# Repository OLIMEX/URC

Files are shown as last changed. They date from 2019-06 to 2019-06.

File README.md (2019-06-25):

# URC
Universal Remote Control soldering kit

How to transfer a command from a remote control to the Olimex URC module:

1. Enter learning mode - press and hold both buttons until red LED turns on, then release both buttons;
2. Assing a button for the new comamnd - press button 1 or button 2 until LED blinks few times then release the button; the red LED remains on;
3. Programming - point the front of the Olimex URC module to the remote control; then press and hold the command you wish to store until the red LED turns off.

## License
* License for the software is GPL3
* License for the hardware is CERN OHL v1.2
* License for the documentation is CC-BY-SA-3.0

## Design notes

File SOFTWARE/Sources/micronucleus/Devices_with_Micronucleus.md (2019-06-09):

# List of devices with Micronucleus (incomplete) #

Micronucleus is widely used on thousands of open hardware product by different vendors. Please submit a pull request to add your own devices to this list, in case you design new hardware employing the Micronucleus bootloader.

Please note that Micronucleus is a completely independent project and is not afilliated in any way with the vendors mentioned below.

## ATtiny85 ##

- [Digispark](http://digistump.com/products/1) by [Digistump](digistump.com) - Widely spread tiny USB Developmentboard with Arduino-Support.

- [Olimexino 85](https://www.olimex.com/Products/Duino/AVR/open-source-hardware) by [Olimex](https://www.olimex.com) - Several different devboards fully assembled or as kits with USB interface

- [Usblinky](https://metalab.at/wiki/Usblinky) by [Metalab](https://metalab.at) - Tiny USB controller for WS2812 RGB LEDs.

- [Nanite 85](https://cpldcpu.wordpress.com/2014/04/25/the-nanite-85/) - Smallest useable ATtiny85 devboard. Approximates DIP ATtiny85 form factor.

- [Wattuino Nanite 85](http://www.watterott.com/en/Wattuino-Nanite85) by [Watterott](http://www.watterott.com) - Manufacturable redesign of the Nanite 85

- [BBtech ATtiny85 board](https://www.tindie.com/products/BBTech/attiny85-usb-development-tool-board/) - Well designed ATtiny85 board in Trinket form factor. Discontinued(?)

- [Iteadduino Tiny](http://imall.iteadstudio.com/im130615003.html) by Itead

- [Pro Nano 85](http://www.jayconsystems.com/pro-nano-50v-attiny85.html) by Jaconsystems

- [LaborTageBadge2013](http://www.das-labor.org/wiki/LaborTageBadge2013) - Badge with ATtiny85

- [Franzininho](https://github.com/Franzininho/franzininho-diy-board) - Franzininho designed by Fábio Souza and Thalis Antunes for Arduino Day 2017 at São Paulo / Brazil.

- [TinyStick](https://gitlab.com/nonchip/tinystick) - A simple open source Attiny85 board in a "usb stick on PCB" form factor simply exposes ISP and PortB without any onboard LED/button pin hogging. by Kyra 'nonchip' Zimmer

## ATtiny 841 ##

- [Wattuino Nanite 841](http://www.watterott.com/de/Wattuino-Nanite841) - Extremely small devboard with ATtiny841. Approximates the form factor of a DIP package.

## ATtiny 167 ##

- [Digispark Pro](http://digistump.com/products/109) by [Digistump](digistump.com) - Digispark successor with more I/O and memory

## ATtiny 84 ##
- [Shinewave](https://github.com/GGreenwood/Shinewave) by [Electric Exploits](http://electricexploits.net/) - USB mods for GameCube controllers

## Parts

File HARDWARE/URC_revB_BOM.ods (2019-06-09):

Designation | Quantity | Designator | Package
SY7080 | 1 | U1 | SOT23-6
56.2K_1% | 1 | R5 | R_0603_5MIL_DWS
100K_1% | 1 | R4 | R_0603_5MIL_DWS
4.7uH NRS4018T4R7MDGJ | 1 | L1 | CD43
SMD КОНД 0805 22 UF 6.3VDC | 3 | C1,C4,C6 | C_0805_5MIL_DWS
SMD КЛЮЧ ТАКТИЛЕН TSW66-V043R-100-LF / T1102NE 6x6x4.3mm | 2 | SW1,SW2
ИС VS1838B | 1 | U3 | RPM7236-V
SMD РЕЗ 0805 2 K 5% | 5 | R14,R13,R12,R10,R9 | R_0805_5MIL_DWS
СВЕТОДИОД IR IR333-A | 1 | LED2 | LED-5mm-PTH-KA
ATTINY85-20PU | 1 | U2 | SO-8
СЪЕДИНИТЕЛ BTH-DP-AA-LF (BH311P) | 1 | BAT1 | BATTERY-1xAA
SMD РЕЗ 1206 4.7 OHM 5% | 1 | R11 | R_1206_5MIL_DWS
SMD РЕЗ 0805 10 K 5% | 4 | R8,R6,R3,R2 | R_0805_5MIL_DWS
SMD РЕЗ 0805 100 K 5% | 1 | R7 | R_0805_5MIL_DWS
SMD РЕЗ 0805 22 K 5% | 1 | R1 | R_0805_5MIL_DWS
LED 3mm RED PTH | 1 | LED1 | LED-3mm-PTH-KA
WNM2016-3/TR | 1 | FET1 | SOT23
SMD КОНД 0805 2.2 UF | 3 | C5,C3,C2 | C_0805_5MIL_DWS

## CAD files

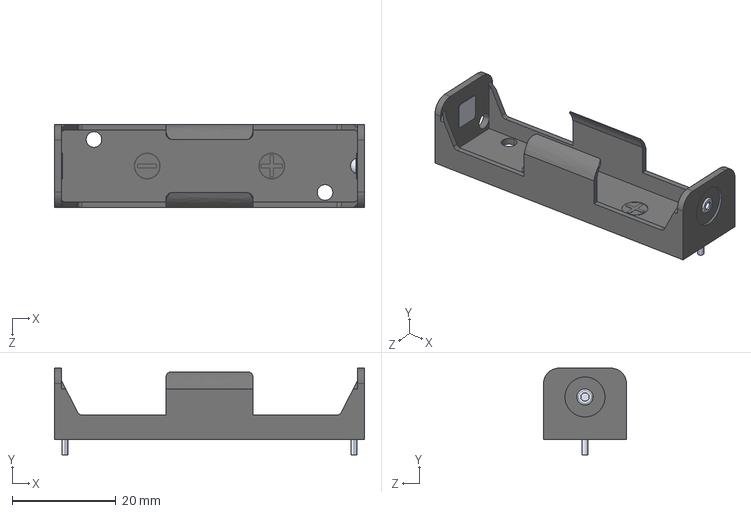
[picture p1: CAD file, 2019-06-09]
HARDWARE/3d/BAT_1xAA_HOLDER.step
59.7 x 16.7 x 16.0 mm

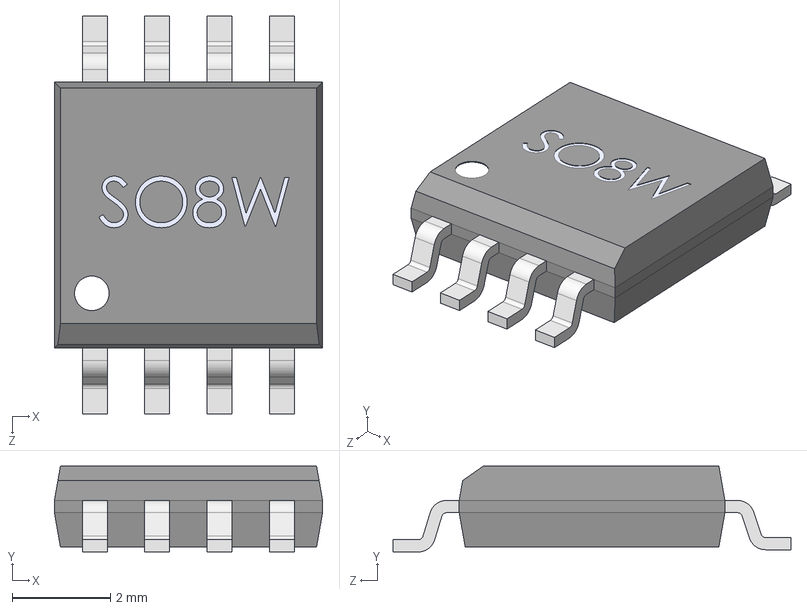
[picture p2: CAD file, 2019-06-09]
HARDWARE/3d/SO-8_208mil---SOIC8_Wide_5mmx5mm.step
5.46 x 1.75 x 8.10 mm

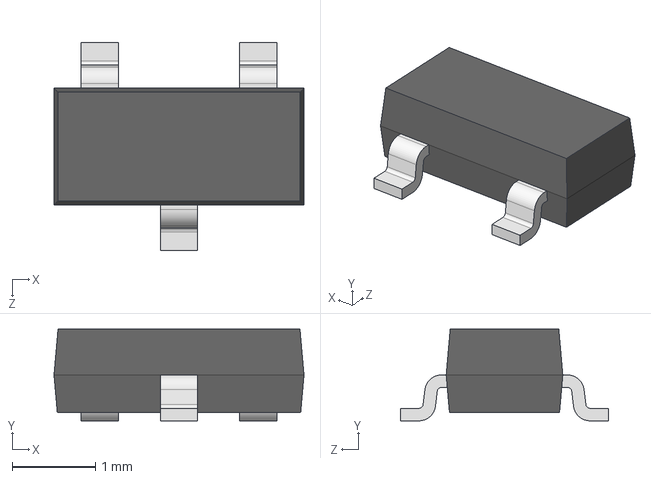
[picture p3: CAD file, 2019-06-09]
HARDWARE/3d/SOT-23.step
3.00 x 1.10 x 2.50 mm

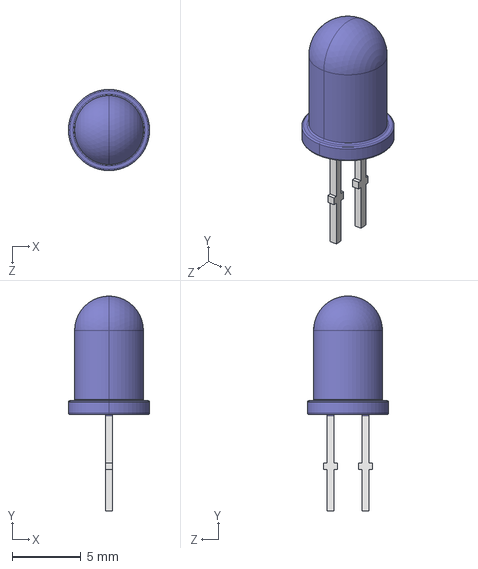
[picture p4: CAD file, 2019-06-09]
HARDWARE/3d/LED5MM.step
5.90 x 15.6 x 5.90 mm

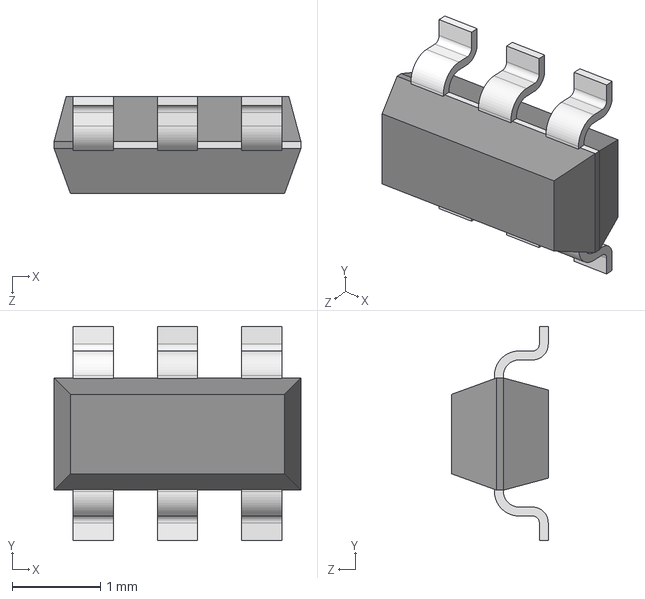
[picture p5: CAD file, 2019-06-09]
HARDWARE/3d/SOT-23-6.step
2.79 x 2.43 x 1.09 mm

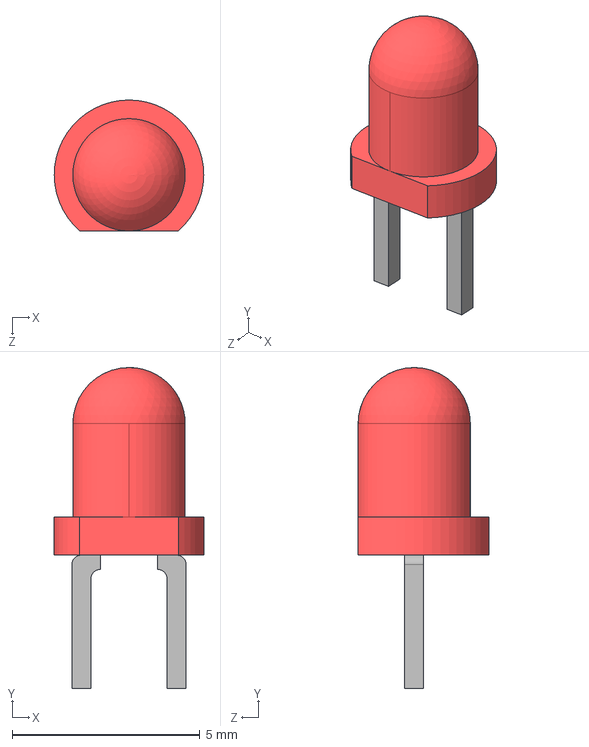
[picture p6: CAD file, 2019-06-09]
HARDWARE/3d/REDLED.step
3.99 x 8.56 x 3.49 mm

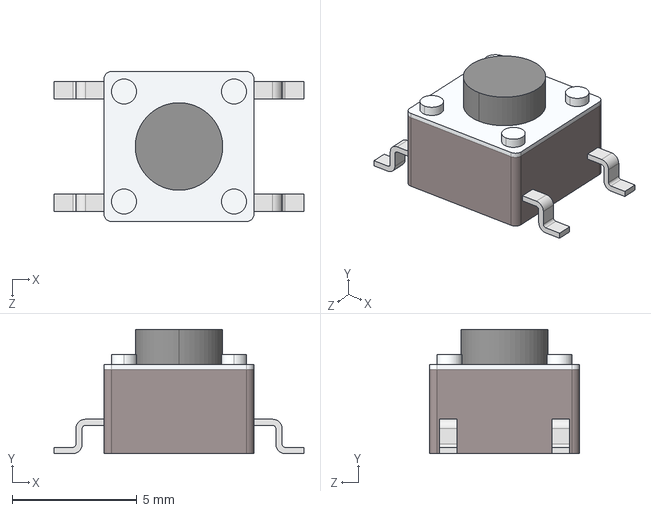
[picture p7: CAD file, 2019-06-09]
HARDWARE/3d/6mmTactileSwitch.step
10.0 x 4.97 x 6.00 mm

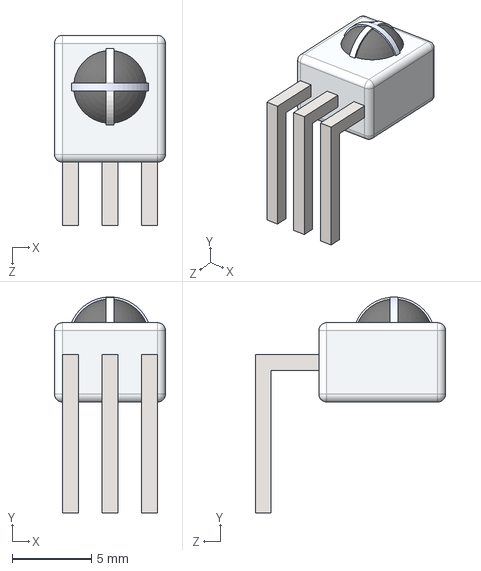
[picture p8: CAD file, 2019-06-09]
HARDWARE/3d/User_Library-Parallax-IR.step
7.00 x 13.6 x 12.0 mm

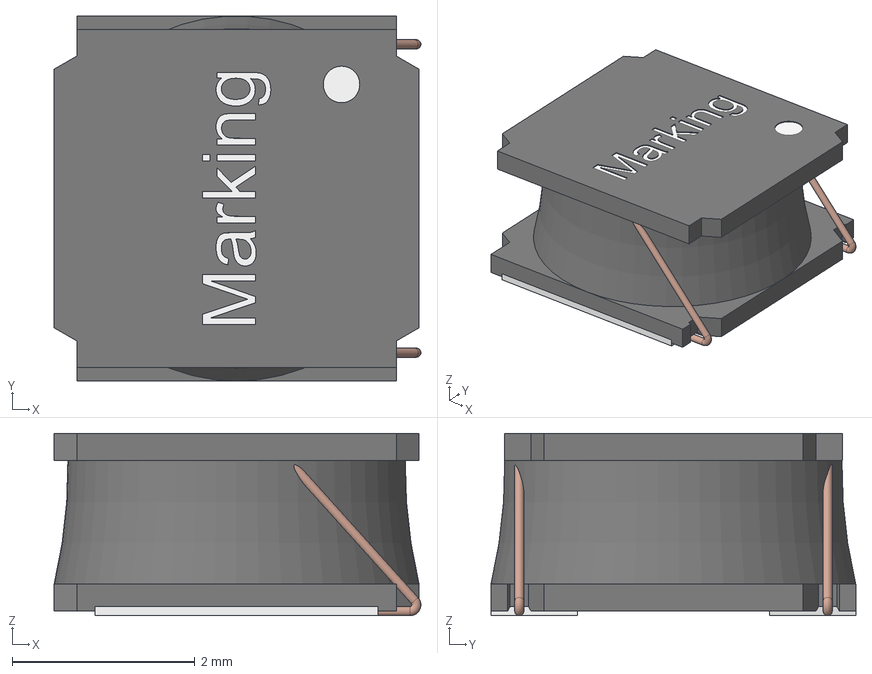
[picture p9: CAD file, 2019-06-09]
HARDWARE/3d/L-CD43_shielded.STEP
4.02 x 4.00 x 2.00 mm
housing
contact x 2
Glue
Wire x 2

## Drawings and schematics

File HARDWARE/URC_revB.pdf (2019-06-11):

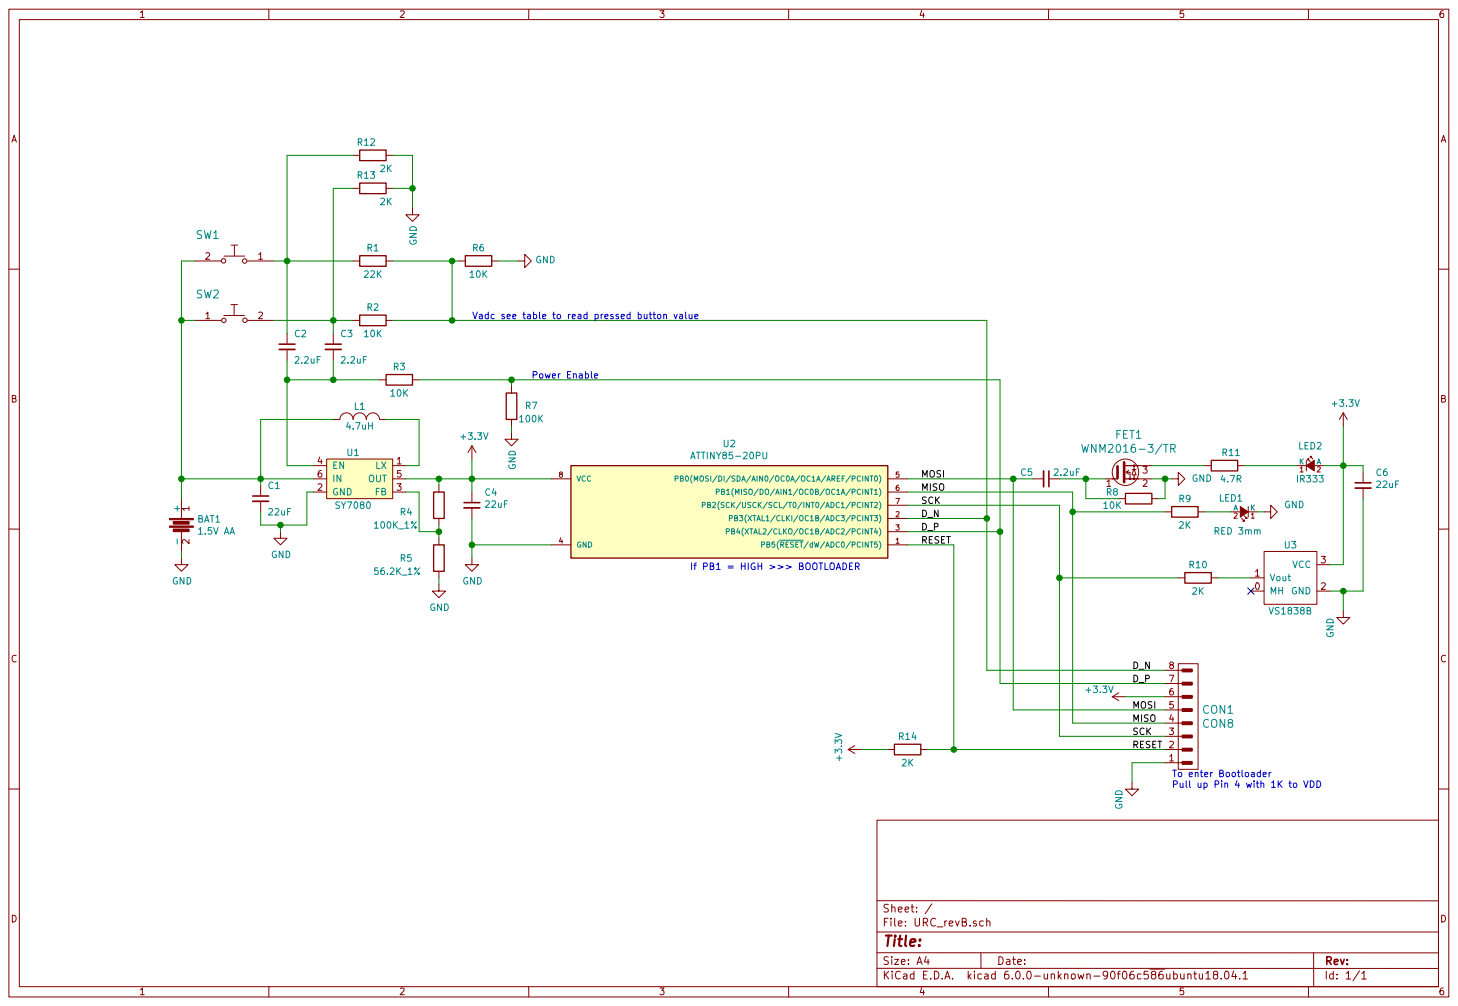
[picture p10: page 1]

If PB1 = HIGH >>> BOOTLOADER GND

RESET SCK MISO MOSI D_P D_N 6 5

To enter Bootloader Pull up Pin 4 with 1K to VDD

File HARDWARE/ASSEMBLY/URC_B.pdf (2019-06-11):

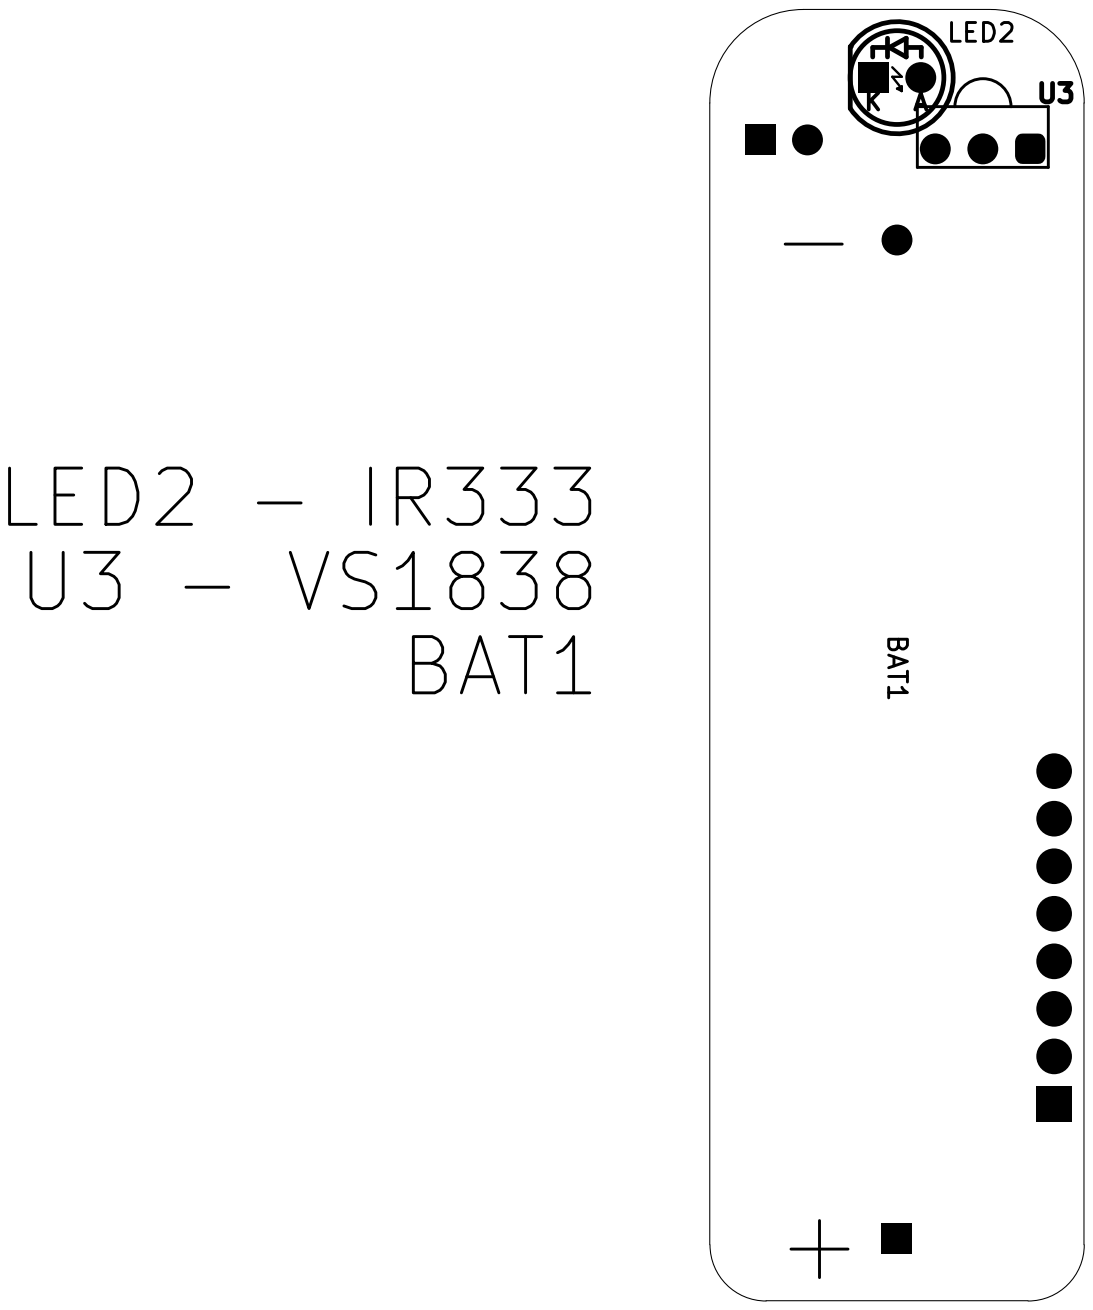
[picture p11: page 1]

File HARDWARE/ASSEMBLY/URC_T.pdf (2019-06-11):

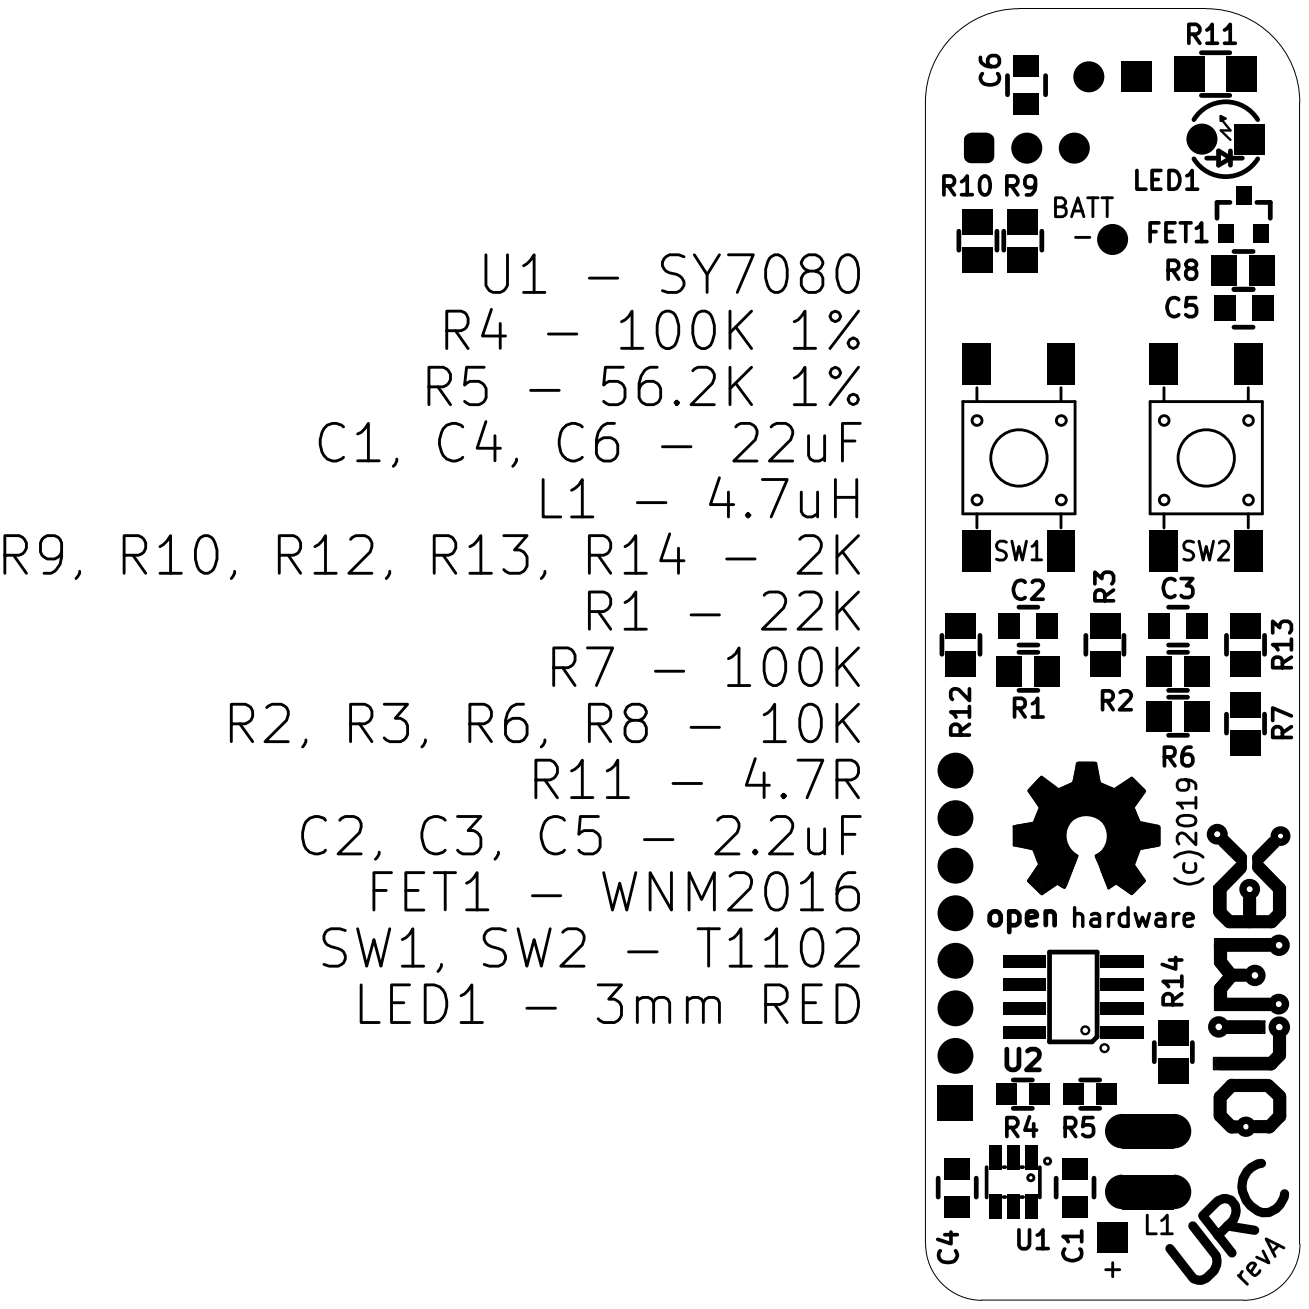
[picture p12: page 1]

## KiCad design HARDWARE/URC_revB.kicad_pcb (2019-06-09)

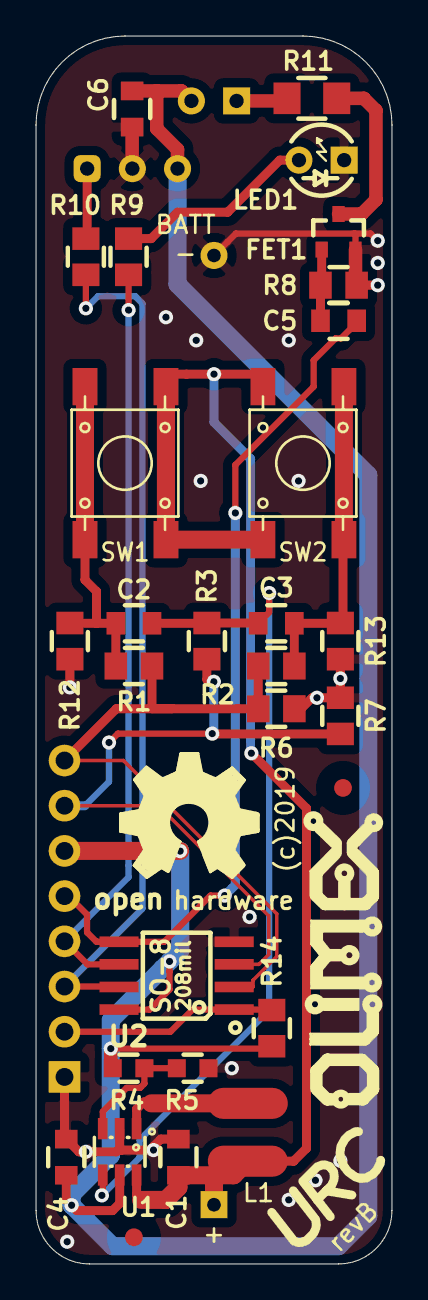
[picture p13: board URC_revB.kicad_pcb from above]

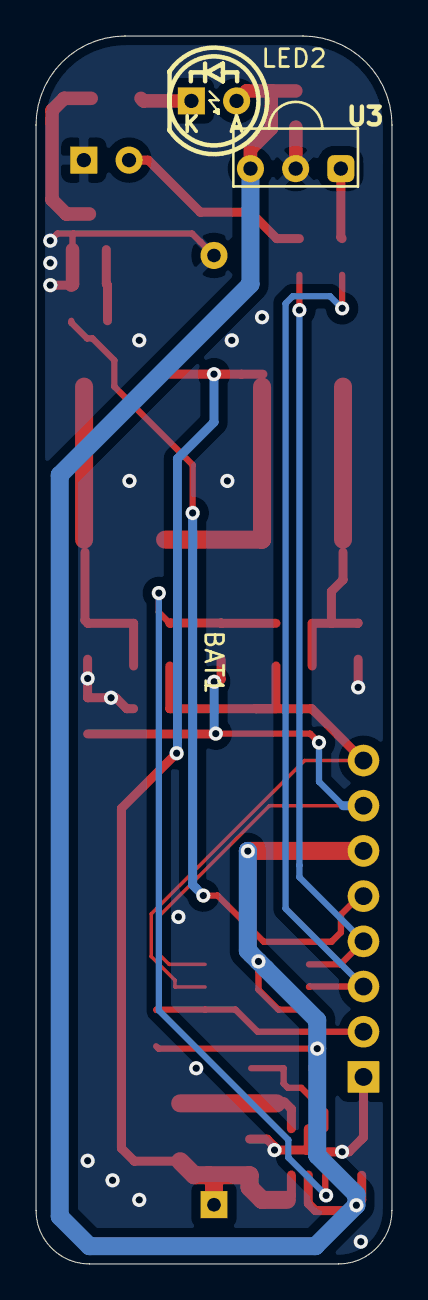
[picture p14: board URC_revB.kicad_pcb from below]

Board: 2 copper layers, 20.0 x 69.0 mm, 33 parts (3 on the bottom side), 19 nets.

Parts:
BAT1: Battery; BATTERY-1xAA
C1, C4, C6: 22uF; C_0805_5MIL_DWS
C2, C3, C5: 2.2uF; C_0805_5MIL_DWS
CON1: CON8; HN1x8
FET1: WNM2016-3/TR; SOT23
L1: 4.7uH; CD43
LED1: RED 3mm; LED-3mm-PTH-KA
LED2: IR333; LED-5mm-PTH-KA
R1: 22K; R_0805_5MIL_DWS
R2, R3, R6, R8: 10K; R_0805_5MIL_DWS
R4: 100K_1%; R_0603_5MIL_DWS
R5: 56.2K_1%; R_0603_5MIL_DWS
R7: 100K; R_0805_5MIL_DWS
R9, R10, R12, R13, R14: 2K; R_0805_5MIL_DWS
R11: 4.7R; R_1206_5MIL_DWS
Ref*: Val**; Fiducial1x3_transp
Ref*#2: Val**; Fiducial1x3_transp
SW1, SW2: T1107A(6x3,8x2,5MM); T1102SMD
U1: SY7080; SOT23-6
U2: ATTINY85-20PU; SO-8_208mil
U3: VS1838B; RPM7236-V

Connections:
+3V3: C4.1, C6.1, CON1.6, LED2.2, R4.1, R14.1, U1.5, U2.8, U3.3
/D_N: CON1.8, R1.2, R2.2, R6.1, U2.2
/D_P: CON1.7, R3.2, R7.2, U2.3
/MISO: CON1.4, R9.1, U2.6
/MOSI: C5.2, CON1.5, U2.5
/RESET: CON1.2, R14.2, U2.1
/SCK: CON1.3, R10.1, U2.7
GND: BAT1.2, C1.2, C4.2, C6.2, CON1.1, FET1.2, LED1.1, R5.2, R6.2, R7.1, R8.2, R12.2, R13.2, U1.2, U2.4, U3.2
unnamed: BAT1.1, C1.1, L1.1, SW1.2, SW2.1, U1.6
unnamed: C2.1, R1.1, R12.1, SW1.1
unnamed: C2.2, C3.2, R3.1, U1.4
unnamed: C3.1, R2.1, R13.1, SW2.2
unnamed: C5.1, FET1.1, R8.1
unnamed: FET1.3, R11.1
unnamed: L1.2, U1.1
unnamed: LED1.2, R9.2
unnamed: LED2.1, R11.2
unnamed: R4.2, R5.1, U1.3
unnamed: R10.2, U3.1

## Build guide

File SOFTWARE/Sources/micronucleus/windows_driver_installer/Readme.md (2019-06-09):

# Windows driver installation with Zadig #

Zadig is an automated windows driver installer for libusb devices. It will automatically create a driver signature, which prevents issues with unsigned drivers on Windows 10 and earlier. The latest version of Zadig can be found here: [http://zadig.akeo.ie/](http://zadig.akeo.ie/). For convenience, a copy is provided in this folder.

Please proceed as follows to install the Micronucleus driver:

1. Run Zadig_2.1.2.exe. The interface, as shown below, appears.
2. In the menu, go to *Device->Load Preset Device*.  Select micronucleus.cfg.
3. Click the "Install Driver" button.

The driver is now installed and Micronucleus should be ready to use. 

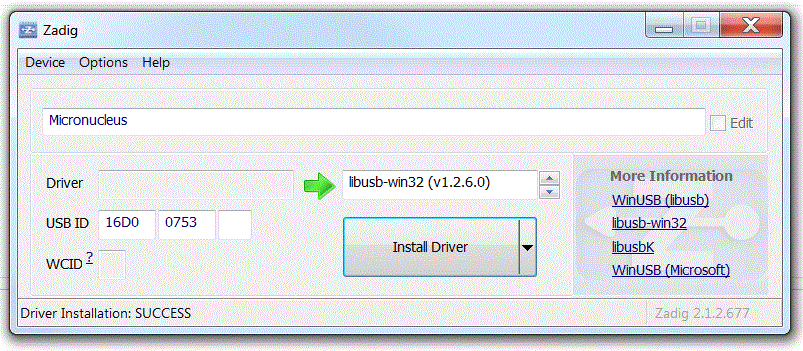
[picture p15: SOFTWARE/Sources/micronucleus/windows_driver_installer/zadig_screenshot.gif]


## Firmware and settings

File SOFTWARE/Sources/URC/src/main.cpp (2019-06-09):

#include <Arduino.h>
#include <EEPROM.h>
#define SYSCLOCK 8000000
#define SAMPLE_SIZE  128
#define IR_SEND_PWM_START    TCCR1 |=  _BV(COM1A0)
#define IR_SEND_PWM_STOP    TCCR1 &= ~(_BV(COM1A0))

const uint16_t pwmval = (SYSCLOCK / 4000 / 36);

int setcounter = 0;
int IRpin = 2;
int IRLED = 0;
int DCDCen = 4;
unsigned int TimerValue[SAMPLE_SIZE];
byte change_count;
long time;
byte mOSCCAL;

// HAL
#define REDLED_ON digitalWrite(1,HIGH)
#define REDLED_OFF digitalWrite(1,LOW)

/*
Input:
TIMEOUT in seconds if no buttons pressed
Return:
0 - no buttons pressed
1 - Left Button pressed
2 - Right Button pressed
3 - Both buttons pressed
*/
int readButtons(int readtimeout){
int a = 0;
  readtimeout = readtimeout * 10;
  readtimeout++;
while (readtimeout > 0){
  delay(100);
  int but = analogRead(A3);
  if (but > 35) a = 1;
  if (but > 150) a = 2;
  if (but > 250) a = 3;
  if (a > 0)  readtimeout = 0;
  readtimeout--;
}
return a;
}

// Turn off power
void PowerOFF(void){
  delay(500);
  REDLED_OFF;
  digitalWrite(DCDCen,LOW);
 while (1);
}

//Flash Red Led a times
void LED_flash(int a){
  while (a > 0){
    delay(666);
  REDLED_ON;
  delay(333);
  REDLED_OFF;
  a--;
  }
}
// End of hal
void SendCommand(int command){

int memTCCR1 = TCCR1;

pinMode(IRLED, OUTPUT);
digitalWrite(IRLED,0);
delay(10);
// Command sending begin:
TCCR1 = _BV(PWM1A)  | _BV(CS12);
OCR1C = pwmval; OCR1A = (pwmval / 3) * 2;
IR_SEND_PWM_STOP;

REDLED_OFF;



  // write to eeprom 0-0xff, 0x100-0x1ff, 0x200-0x2ff
  int addr = (command - 1) * 0x100;

  change_count = 0;
  while (change_count < SAMPLE_SIZE) {
  byte highByte = EEPROM.read(addr++);
  byte lowByte = EEPROM.read(addr++);

  TimerValue[change_count++] = ((highByte << 8) & 0xFF00) + lowByte;
}

cli();
OSCCAL = mOSCCAL;
change_count = 0;
while (change_count < SAMPLE_SIZE) {

// set pwm on/off
    if (TimerValue[change_count] & 0x8000)
      {
      IR_SEND_PWM_STOP;
      if (TimerValue[change_count] == 0xffff) break;
      TimerValue[change_count] &= 0x7fff;

      }
      else
      {
      IR_SEND_PWM_START;
      }


// do delay

      TIFR |= _BV(TOV1);
        while (TimerValue[change_count])
        {
          if (bitRead(TIFR,TOV1))      //(TIFR & _BV(TOV1))
            {
              TimerValue[change_count]--;
              TIFR |= _BV(TOV1);
            }
        };
      change_count++;
  }




IR_SEND_PWM_STOP;
  REDLED_OFF;
TCCR1 = memTCCR1;
sei();

  delay(200);

}

void LearnCommands(int readtimeout){
int direction = 0;


delay(5);
REDLED_ON;
//wait to release buttons
  while (readButtons(0) > 0);
// read which buttons command to learn
int button = readButtons(10);
REDLED_OFF;
if (button == 0) PowerOFF();  // if no buttons pressed -> power off
else {
// indicate button#
 LED_flash(button);
}
delay(500);

cli();

// Command learning begin:
TCCR1 = _BV(PWM1A)  | _BV(CS12);// | _BV(CS10);
OCR1C = pwmval; OCR1A = (pwmval / 3) * 2;

pinMode(IRLED,INPUT);

pinMode(IRpin, INPUT_PULLUP);
//while(digitalRead(IRpin) == LOW);
IR_SEND_PWM_STOP;
change_count = 0;

OSCCAL = mOSCCAL;
REDLED_ON;
// wait for start frame
while(digitalRead(IRpin) == HIGH);


  while (change_count < SAMPLE_SIZE) {

    TimerValue[change_count] = 0;
    TIFR |= _BV(TOV1);
// low time
      while(digitalRead(IRpin) == LOW)
        {
          if (bitRead(TIFR,TOV1))
            {
              TimerValue[change_count]++;
              TIFR |= _BV(TOV1);
            }
        };
      change_count++;
//high time
    TimerValue[change_count]=0x8000;
    TIFR |= _BV(TOV1);
      while(digitalRead(IRpin) == HIGH)
      {
        if (bitRead(TIFR,TOV1))      //(TIFR & _BV(TOV1))
          {
            TimerValue[change_count]++;
            TIFR |= _BV(TOV1);
            if (TimerValue[change_count] > 0x9000)
            {
              while (change_count < SAMPLE_SIZE )
                        TimerValue[change_count++] = 0xFFFF;
                              break;
            }
          }
      };

      change_count++;
    }
  // code received
// store code button = 1 || 2 || 3
change_count = 0;
// write to eeprom 0-0xff, 0x100-0x1ff, 0x200-0x2ff
int addr = (button - 1) * 0x100;

while (change_count < SAMPLE_SIZE)
      {
      EEPROM.write(addr++,TimerValue[change_count]>>8);
      EEPROM.write(addr++,TimerValue[change_count++] & 0xff);

      }

REDLED_OFF;
PowerOFF();
}


void setup() {

  // put your setup code here, to run once:
 mOSCCAL = OSCCAL;
  pinMode(DCDCen, OUTPUT);
  digitalWrite(DCDCen,HIGH);
  pinMode(IRpin, INPUT);
  pinMode(3, INPUT);
  pinMode(1, OUTPUT);
  pinMode(IRLED, INPUT);
  digitalWrite(IRLED,0);
  //TCCR0A = 0;           // turn off frequency generator (should be off already)
  //TCCR0B = 0;           // turn off frequency generator (should be off already)
  //TCCR1A = _BV(COM0A0); TCCR0B = _BV(WGM01) | _BV(CS00);
  pinMode(IRpin, INPUT_PULLUP);
  delay(5);

//  delay(50);
  REDLED_OFF;
  delay(5);
  IR_SEND_PWM_STOP;
delay(50);
int a = readButtons(0);
delay(350);
if (a < 3)
SendCommand(a);

}

void loop() {
  // put your main code here, to run repeatedly:
//delay(1000);
int a = readButtons(0);
if (a == 0) PowerOFF();
else {
      if (a == 3) {
        setcounter++;
        delay(1000);
      }
      else SendCommand(a);
      if (setcounter > 4) LearnCommands(10);

  }
}

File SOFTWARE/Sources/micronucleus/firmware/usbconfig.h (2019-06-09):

/* Name: usbconfig.h
 * Project: V-USB, virtual USB port for Atmel's(r) AVR(r) microcontrollers
 * Author: Christian Starkjohann
 * Creation Date: 2005-04-01
 * Tabsize: 4
 * Copyright: (c) 2005 by OBJECTIVE DEVELOPMENT Software GmbH
 * License: GNU GPL v2 (see License.txt), GNU GPL v3 or proprietary (CommercialLicense.txt)
 * This Revision: $Id: usbconfig.h 799 2010-07-27 17:30:13Z cs $
 */

#ifndef __usbconfig_h_included__
#define __usbconfig_h_included__

/* YOU SHOULD NOT NEED TO MODIFY THIS FILE! All configurations are supposed
 * to go into bootloaderconfig.h!
 */

/* ---------------------------- Hardware Config ---------------------------- */

/* All the port and pin assignments, as well as the clock speed and CRC
   setting are now in bootloaderconfig.h: */

#include "bootloaderconfig.h"

/* --------------------------- Functional Range ---------------------------- */

#define USB_CFG_HAVE_INTRIN_ENDPOINT    0
/* Define this to 1 if you want to compile a version with two endpoints: The
 * default control endpoint 0 and an interrupt-in endpoint (any other endpoint
 * number).
 */
#define USB_CFG_HAVE_INTRIN_ENDPOINT3   0
/* Define this to 1 if you want to compile a version with three endpoints: The
 * default control endpoint 0, an interrupt-in endpoint 3 (or the number
 * configured below) and a catch-all default interrupt-in endpoint as above.
 * You must also define USB_CFG_HAVE_INTRIN_ENDPOINT to 1 for this feature.
 */
#define USB_CFG_EP3_NUMBER              3
/* If the so-called endpoint 3 is used, it can now be configured to any other
 * endpoint number (except 0) with this macro. Default if undefined is 3.
 */
/* #define USB_INITIAL_DATATOKEN           USBPID_DATA1 */
/* The above macro defines the startup condition for data toggling on the
 * interrupt/bulk endpoints 1 and 3. Defaults to USBPID_DATA1.
 * Since the token is toggled BEFORE sending any data, the first packet is
 * sent with the oposite value of this configuration!
 */
#define USB_CFG_IMPLEMENT_HALT          0
/* Define this to 1 if you also want to implement the ENDPOINT_HALT feature
 * for endpoint 1 (interrupt endpoint). Although you may not need this feature,
 * it is required by the standard. We have made it a config option because it
 * bloats the code considerably.
 */
#define USB_CFG_SUPPRESS_INTR_CODE      0
/* Define this to 1 if you want to declare interrupt-in endpoints, but don't
 * want to send any data over them. If this macro is defined to 1, functions
 * usbSetInterrupt() and usbSetInterrupt3() are omitted. This is useful if
 * you need the interrupt-in endpoints in order to comply to an interface
 * (e.g. HID), but never want to send any data. This option saves a couple
 * of bytes in flash memory and the transmit buffers in RAM.
 */
#define USB_CFG_INTR_POLL_INTERVAL      10
/* If you compile a version with endpoint 1 (interrupt-in), this is the poll
 * interval. The value is in milliseconds and must not be less than 10 ms for
 * low speed devices.
 */
#ifndef USB_CFG_IS_SELF_POWERED // allow bootloaderconfig.h to override
#define USB_CFG_IS_SELF_POWERED         0
#endif
/* Define this to 1 if the device has its own power supply. Set it to 0 if the
 * device is powered from the USB bus.
 */
#ifndef USB_CFG_MAX_BUS_POWER   // allow bootloaderconfig.h to override
#define USB_CFG_MAX_BUS_POWER           100
#endif
/* Set this variable to the maximum USB bus power consumption of your device.
 * The value is in milliamperes. [It will be divided by two since USB
 * communicates power requirements in units of 2 mA.]
 */
#define USB_CFG_IMPLEMENT_FN_WRITE      0
/* Set this to 1 if you want usbFunctionWrite() to be called for control-out
 * transfers. Set it to 0 if you don't need it and want to save a couple of
 * bytes.
 */
#define USB_CFG_IMPLEMENT_FN_READ       0
/* Set this to 1 if you need to send control replies which are generated
 * "on the fly" when usbFunctionRead() is called. If you only want to send
 * data from a static buffer, set it to 0 and return the data from
 * usbFunctionSetup(). This saves a couple of bytes.
 */
#define USB_CFG_IMPLEMENT_FN_WRITEOUT   0
/* Define this to 1 if you want to use interrupt-out (or bulk out) endpoints.
 * You must implement the function usbFunctionWriteOut() which receives all
 * interrupt/bulk data sent to any endpoint other than 0. The endpoint number
 * can be found in 'usbRxToken'.
 */
#define USB_CFG_HAVE_FLOWCONTROL        0
/* Define this to 1 if you want flowcontrol over USB data. See the definition
 * of the macros usbDisableAllRequests() and usbEnableAllRequests() in
 * usbdrv.h.
 */
#define USB_CFG_DRIVER_FLASH_PAGE       0
/* If the device has more than 64 kBytes of flash, define this to the 64 k page
 * where the driver's constants (descriptors) are located. Or in other words:
 * Define this to 1 for boot loaders on the ATMega128.
 */
#define USB_CFG_LONG_TRANSFERS          0
/* Define this to 1 if you want to send/receive blocks of more than 254 bytes
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

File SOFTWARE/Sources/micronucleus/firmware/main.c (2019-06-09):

/* 
 * Project: Micronucleus -  v2.04
 *
 * Micronucleus V2.04             (c) 2016 Tim Bo"scke - cpldcpu@gmail.com
 *                               (c) 2014 Shay Green
 * Original Micronucleus         (c) 2012 Jenna Fox
 *
 * Based on USBaspLoader-tiny85  (c) 2012 Louis Beaudoin
 * Based on USBaspLoader         (c) 2007 by OBJECTIVE DEVELOPMENT Software GmbH
 *
 * License: GNU GPL v2 (see License.txt)
 */
 
#define MICRONUCLEUS_VERSION_MAJOR 2
#define MICRONUCLEUS_VERSION_MINOR 4

#include <avr/io.h>
#include <avr/pgmspace.h>
#include <avr/wdt.h>
#include <avr/boot.h>
#include <util/delay.h>

#include "bootloaderconfig.h"
#include "usbdrv/usbdrv.c"

// verify the bootloader address aligns with page size
#if (defined __AVR_ATtiny841__)||(defined __AVR_ATtiny441__)  
  #if BOOTLOADER_ADDRESS % ( SPM_PAGESIZE * 4 ) != 0
    #error "BOOTLOADER_ADDRESS in makefile must be a multiple of chip's pagesize"
  #endif
#else
  #if BOOTLOADER_ADDRESS % SPM_PAGESIZE != 0
    #error "BOOTLOADER_ADDRESS in makefile must be a multiple of chip's pagesize"
  #endif  
#endif

#if SPM_PAGESIZE>256
  #error "Micronucleus only supports pagesizes up to 256 bytes"
#endif

#if ((AUTO_EXIT_MS>0) && (AUTO_EXIT_MS<1000))
  #error "Do not set AUTO_EXIT_MS to below 1s to allow Micronucleus to function properly"
#endif

// Device configuration reply
// Length: 6 bytes
//   Byte 0:  User program memory size, high byte
//   Byte 1:  User program memory size, low byte   
//   Byte 2:  Flash Pagesize in bytes
//   Byte 3:  Page write timing in ms. 
//    Bit 7 '0': Page erase time equals page write time
//    Bit 7 '1': Page erase time equals page write time divided by 4
//   Byte 4:  SIGNATURE_1
//   Byte 5:  SIGNATURE_2 

PROGMEM const uint8_t configurationReply[6] = {
  (((uint16_t)PROGMEM_SIZE) >> 8) & 0xff,
  ((uint16_t)PROGMEM_SIZE) & 0xff,
  SPM_PAGESIZE,
  MICRONUCLEUS_WRITE_SLEEP,
  SIGNATURE_1,
  SIGNATURE_2
};  

  typedef union {
    uint16_t w;
    uint8_t b[2];
  } uint16_union_t;
  
#if OSCCAL_RESTORE_DEFAULT
  register uint8_t      osccal_default  asm("r2");
#endif 

register uint16_union_t currentAddress  asm("r4");  // r4/r5 current progmem address, used for erasing and writing 
register uint16_union_t idlePolls       asm("r6");  // r6/r7 idlecounter

// command system schedules functions to run in the main loop
enum {
  cmd_local_nop=0, 
  cmd_device_info=0,
  cmd_transfer_page=1,
  cmd_erase_application=2,
  cmd_write_data=3,
  cmd_exit=4,
  cmd_write_page=64  // internal commands start at 64
};
register uint8_t        command         asm("r3");  // bind command to r3 

// Definition of sei and cli without memory barrier keyword to prevent reloading of memory variables
#define sei() asm volatile("sei")
#define cli() asm volatile("cli")
#define nop() asm volatile("nop")
#define wdr() asm volatile("wdr")

// Use the old delay routines without NOP padding. This saves memory.
#define __DELAY_BACKWARD_COMPATIBLE__   

/* ------------------------------------------------------------------------ */
static inline void eraseApplication(void);
static void writeFlashPage(void);
static void writeWordToPageBuffer(uint16_t data);
static uint8_t usbFunctionSetup(uint8_t data[8]);
static inline void leaveBootloader(void);

// This function is never called, it is just here to suppress a compiler warning.
USB_PUBLIC usbMsgLen_t usbFunctionDescriptor(struct usbRequest *rq) { return 0; }

// erase all pages until bootloader, in reverse order (so our vectors stay in place for as long as possible)
// to minimise the chance of leaving the device in a state where the bootloader wont run, if there's power failure
// during upload
static inline void eraseApplication(void) {
  uint16_t ptr = BOOTLOADER_ADDRESS;

  while (ptr) {
#if (defined __AVR_ATtiny841__)||(defined __AVR_ATtiny441__)    
    ptr -= SPM_PAGESIZE * 4;        
#else
    ptr -= SPM_PAGESIZE;        
#endif    
    boot_page_erase(ptr);
#if (defined __AVR_ATmega328P__)||(defined __AVR_ATmega168P__)||(defined __AVR_ATmega88P__)
    // the ATmegaATmega328p/168p/88p don't halt the CPU when writing to RWW flash, so we need to wait here
    boot_spm_busy_wait();
#endif    
  }
  
  // Reset address to ensure the reset vector is written first.
  currentAddress.w = 0;   
}

// simply write currently stored page in to already erased flash memory
static inline void writeFlashPage(void) {
  if (currentAddress.w - 2 <BOOTLOADER_ADDRESS) {
    boot_page_write(currentAddress.w - 2);   // will halt CPU, no waiting required
#if (defined __AVR_ATmega328P__)||(defined __AVR_ATmega168P__)||(defined __AVR_ATmega88P__)
    // the ATmega328p/168p/88p don't halt the CPU when writing to RWW flash
    boot_spm_busy_wait();
#endif
  }
}

// Write a word into the page buffer.
// Will patch the bootloader reset vector into the main vectortable to ensure
// the device can not be bricked. Saving user-reset-vector is done in the host 
// tool, starting with firmware V2
static void writeWordToPageBuffer(uint16_t data) {

#ifndef ENABLE_UNSAFE_OPTIMIZATIONS     
  #if BOOTLOADER_ADDRESS < 8192
  // rjmp
  if (currentAddress.w == RESET_VECTOR_OFFSET * 2) {
    data = 0xC000 + (BOOTLOADER_ADDRESS/2) - 1;
  }
  #else
  // far jmp
  if (currentAddress.w == RESET_VECTOR_OFFSET * 2) {
    data = 0x940c;
  } else if (currentAddress.w == (RESET_VECTOR_OFFSET +1 ) * 2) {
    data = (BOOTLOADER_ADDRESS/2);
  }    
  #endif
#endif

#if OSCCAL_SAVE_CALIB
   if (currentAddress.w == BOOTLOADER_ADDRESS - TINYVECTOR_OSCCAL_OFFSET) {
      data = OSCCAL;
   }     
#endif
  boot_page_fill(currentAddress.w, data);
  currentAddress.w += 2;
}
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
